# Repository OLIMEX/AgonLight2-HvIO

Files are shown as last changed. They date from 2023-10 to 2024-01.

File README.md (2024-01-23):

# AgonLight2-HvIO
High voltage optoisolated Four outputs and Four inputs and two Temperature sensor connectors for AgonLight2

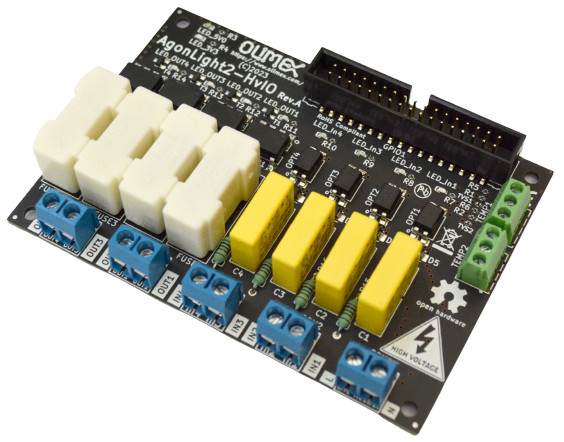
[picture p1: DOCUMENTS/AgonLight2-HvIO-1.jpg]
AgonLight2-HvIO-1


https://www.olimex.com/Products/Retro-Computers/AgonLight2-HvIO/open-source-hardware

Features:

* AgonLight GPIO connector
* Four SSR relays 240VAC 1A
* Four optoisolated inputs 120-240VAC
* Two Dallas18B20 temperature sensors
* LED output indicators
* LED input indicators
* Power supply 3.3V and 5V LED indicators
* Dimensions 100x70mm

## Licenses

* Hardware is released under CERN Open Hardware Licence Version 2 - Strongly Reciprocal, all silkscreen credits to Olimex should remain;
* Software is released under GPL3 Licensee
* Documentation is released under CC BY-SA 4.0

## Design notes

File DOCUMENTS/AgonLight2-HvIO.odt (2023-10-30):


AgonLight2-HvIO

User Manual

Rev.1.0 October 2023 olimex.com

# Introduction to AgonLight2-HvIO

AgonLight2-HvIO (https://www.olimex.com/Products/Retro-Computers/AgonLight2-HvIO/open-source-hardware) is Open Source Hardware board designed to work with AgonLight2.

It has these features:

- Four Solid-State-Relays SSR capable working on 240VAC with 1 A loads connected to AgonLight2 GPIO outputs
- SSR are with zero cross switching noise free
- Four opto isolated 240VAC inputs connected to AgonLight2 GPIO inputs
- Status LEDs for each output and input
- Status LEDs for 3.3V and 5V power supply of AginLight2
- Two Dallas DS18B20 temperature sensor inputs capable to work with SNS-TMP-DS18B20 (https://www.olimex.com/Products/Components/Sensors/Temperature/SNS-TMP-DS18B20/)
- Dimensions 100x70 mm

## Order codes for AgonLight2-HvIO:

AgonLight2-HvIO (https://www.olimex.com/Products/Retro-Computers/AgonLight2-HvIO/open-source-hardware) AgonLight high voltage IO board

SNS-TMP-DS18B20 (https://www.olimex.com/Products/Components/Sensors/Temperature/SNS-TMP-DS18B20/) temparature sensor

CABLE-IDC34-15CM not available yet cable between AgonLight2 and AgonLight2-HvIO

# HARDWARE

## AgonLight2-HvIO layout:

AgonLight2 GPIO connector

Power supply status LEDs

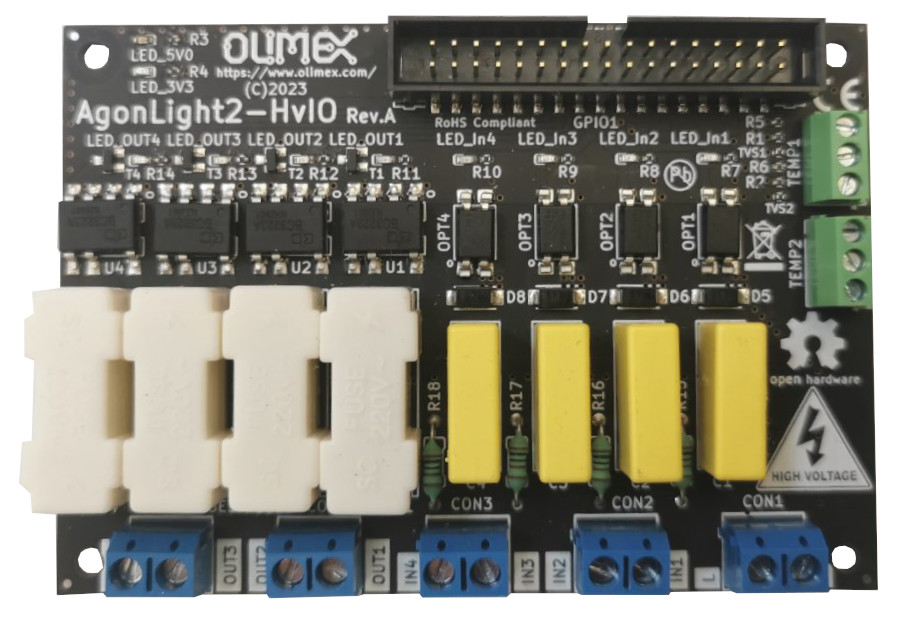
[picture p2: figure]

Temperature Sensors DS18B20

High voltage Outputs

High voltage Inputs

Power supply Live and Neutral

## AgonLight2-HvIO schematic

The schematic of AgonLight2-HvIO (https://www.olimex.com/Products/Retro-Computers/AgonLight2-HvIO/open-source-hardware) is on GitHub. On the next page there is picture of it.

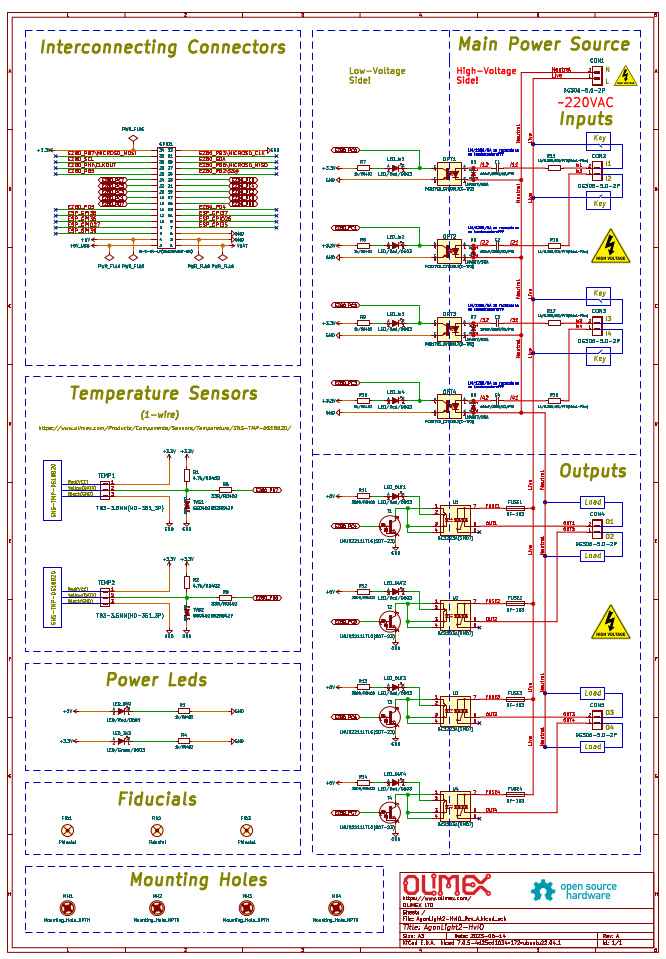
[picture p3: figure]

## AgonLight2 GPIO connector:

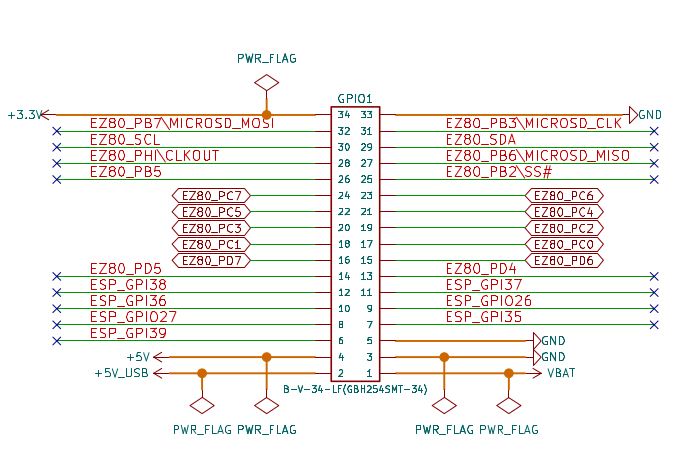
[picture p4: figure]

## AgonLight2-HvIO temperature sensors connector:

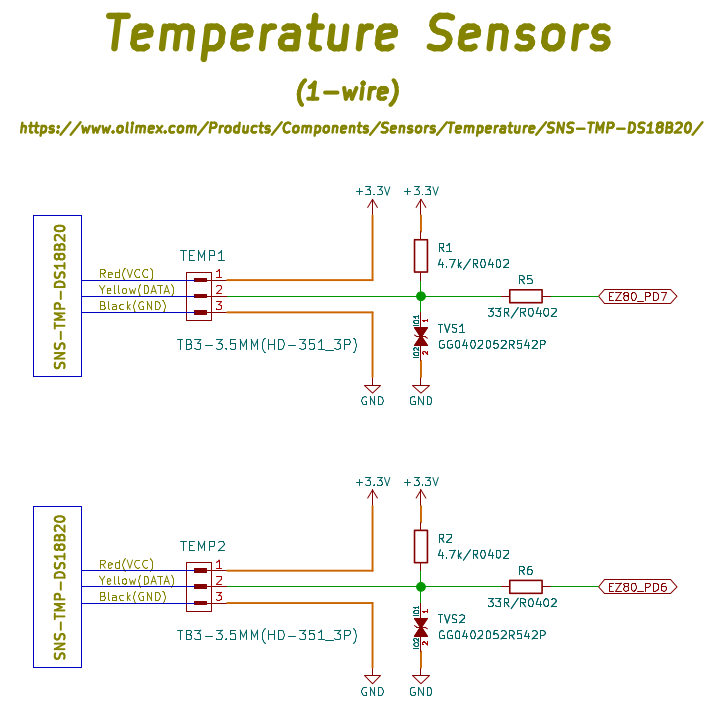
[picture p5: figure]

# SOFTWARE:

(https://www.olimex.com/Products/Retro-Computers/ESP32-SBC-FabGL/open-source-hardware)

## Reading the Inputs and Writing to the Outputs:

The outputs are assigned as follows:

OUT1 → PC4

OUT2 → PC5

OUT3 → PC6

OUT4 → PC7

The inputs are assigned as follows:

IN1 → PC0

IN2 → PC1

IN3 → PC2

IN4 → PC3

Port-C Data Direction Register is at address 159. To make port Input 1 should be written in the corresponding bit, to make it Output 0 should be written.

To make PC0-3 as inputs and PC4-7 as outputs the following basic command should be executed:

PUT 159 , %00001111

Port-C Data Value register is at address 158, so to read the Port-C status you can use:

PRINT GET(158)

and to set OUT1 = HIGH

PUT 158, %00010000

to set OUT1 = LOW

PUT 158, %00000000

Here is sample test program:

10 PC_DR% = &9E
20 PC_DDR% = &9F
30 PC_ALT1% = &A0
40 PC_ALT2% = &A1
50 PD_DR% = &A2
60 PD_DDR% = &A3
70 PD_ALT1% = &A4
80 PD_ALT2% = &A5
90 PUT PC_DDR%, &F
100 PUT PC_ALT1%, &00
110 PUT PC_ALT2%, &00
120 PUT PD_DDR%, &FF
130 I=0
140 Input=0
150 PCD = GET(PC_DR%)
160 Input = Input OR ((PCD EOR &F) AND &F)
170 PRINT "PCD="; PCD; " Input=";Input; " I="; I
180 I=I+1
190 IF (I<10) THEN GOTO 150
200 PUT PC_DR%, Input*16
210 Temp = GET(PD_DR%) AND &C0
220 IF (Temp = &C0) THEN GOTO 130
230 PUT PC_DR%, (GET(PC_DR%) AND &3F) OR ((GET(PD_DR%) AND &C0)EOR &C0)
240 PCD = GET(PC_DR%) AND &F
250 IF (PCD=15) THEN GOTO 230 ELSE GOTO 130

# Revision History

Revision 1.0 October 2023 initial

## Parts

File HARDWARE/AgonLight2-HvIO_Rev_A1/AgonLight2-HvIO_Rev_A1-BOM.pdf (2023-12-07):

AgonLight2-HvIO_Rev_A1-BOM | 10/30/2023
Quantity | Designation | Footprint | Designator
2 | 33R/R0402 | R0402 | R5,R6
4 | 200R/R0402 | R0402 | R11,R12,R13,R14
4 | 1k/0.25W/1%/PTH(Metal-Film) | R_0.25W_PTH | R15,R16,R17,R18
6 | 1k/R0402 | R0402 | R3,R4,R7,R8,R9,R10
2 | 4.7k/R0402 | R0402 | R1,R2
4 | 100nF/250V/X2/PTH | C600-700x250mils | C1,C2,C3,C4
4 | 1N4007/SMA | SMA | D5,D6,D7,D8
2 | GG0402052R542P | D0402 | TVS1,TVS2
9 | LED/Red/0603 | LED_0603 | LED_In1,LED_In2,LED_In3,LED_In4, LED_OUT1,LED_OUT2,LED_OUT3, LED_OUT4,LED_5V0
1 | LED/Green/0603 | LED_0603 | LED_3V3
4 | LMUN2211LT1G(SOT-23) | SOT-23 | T1,T2,T3,T4
4 | BC3213A(SMD7) | SMD7 | U1,U2,U3,U4
4 | PC817CS_CYPC817(C-TP2) | H11A817C_SMD | OPT1,OPT2,OPT3,OPT4
4 | BF-103 | FUSE-HOLDER | FUSE1,FUSE2,FUSE3,FUSE4
1 | B-V-34-LF(GBH254SMT-34) | GBH254SMT-34 | GPIO1
5 | DG306-5.0-2P | TB2-DG306-5.0_2P | CON1,CON2,CON3,CON4,CON5
2 | TB3-3.5ММ(HD-351_3P) | TB3-3.5mm | TEMP1,TEMP2

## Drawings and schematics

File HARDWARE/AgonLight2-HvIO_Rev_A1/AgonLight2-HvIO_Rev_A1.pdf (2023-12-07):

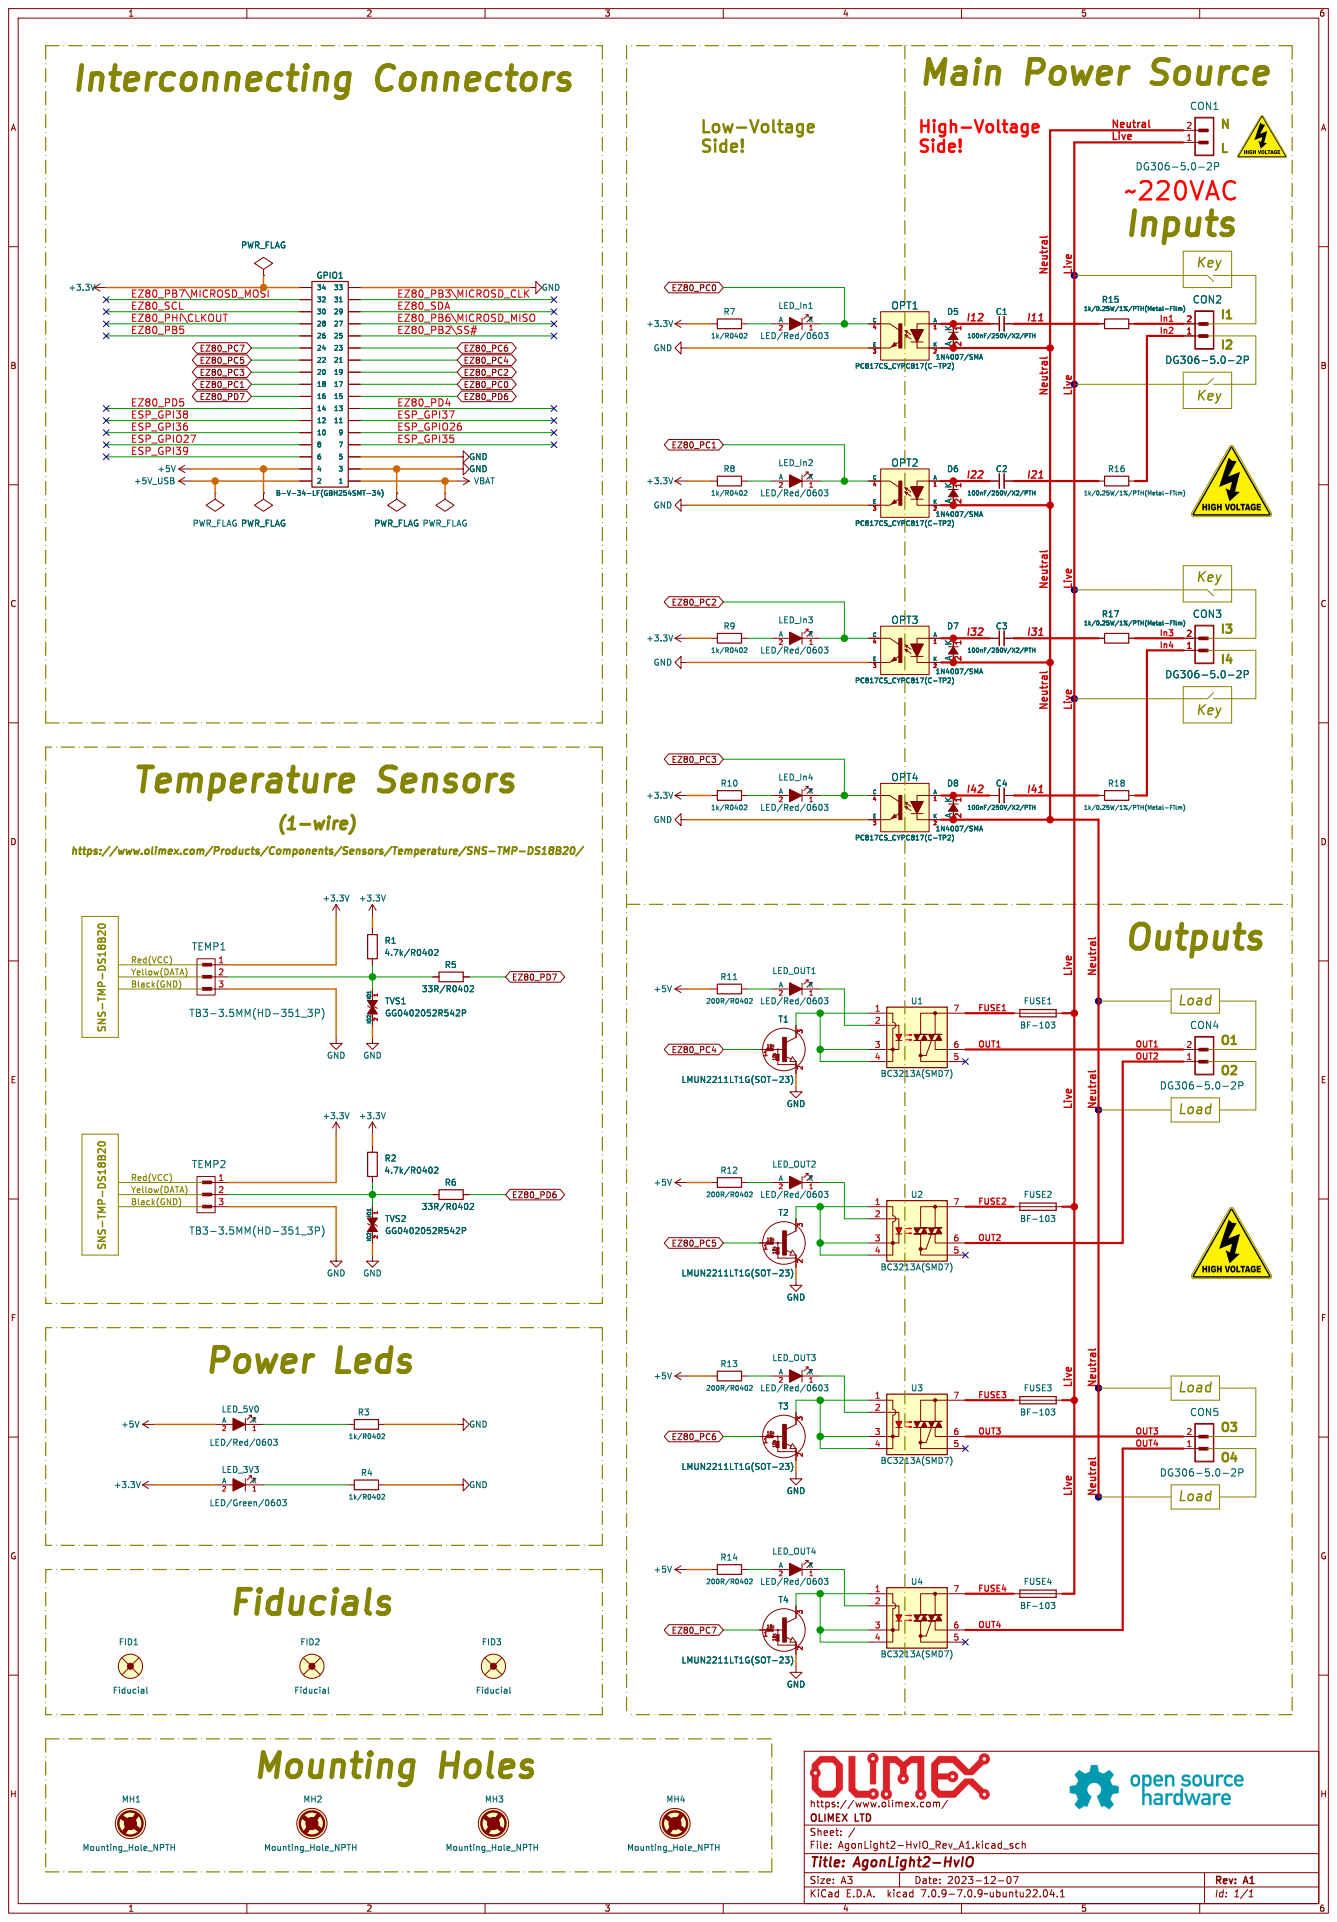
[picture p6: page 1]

https://www.olimex.com/Products/Components/Sensors/Temperature/SNS-TMP-DS18B20/ Temperature Sensors

Outputs Red(VCC) Black(GND) Yellow(DATA)
Mounting Holes SNS-TMP-DS18B20

Yellow(DATA) Red(VCC) Black(GND)

https://www.olimex.com/
File: AgonLight2-HvIO_Rev_A1.kicad_sch Sheet: / OLIMEX LTD

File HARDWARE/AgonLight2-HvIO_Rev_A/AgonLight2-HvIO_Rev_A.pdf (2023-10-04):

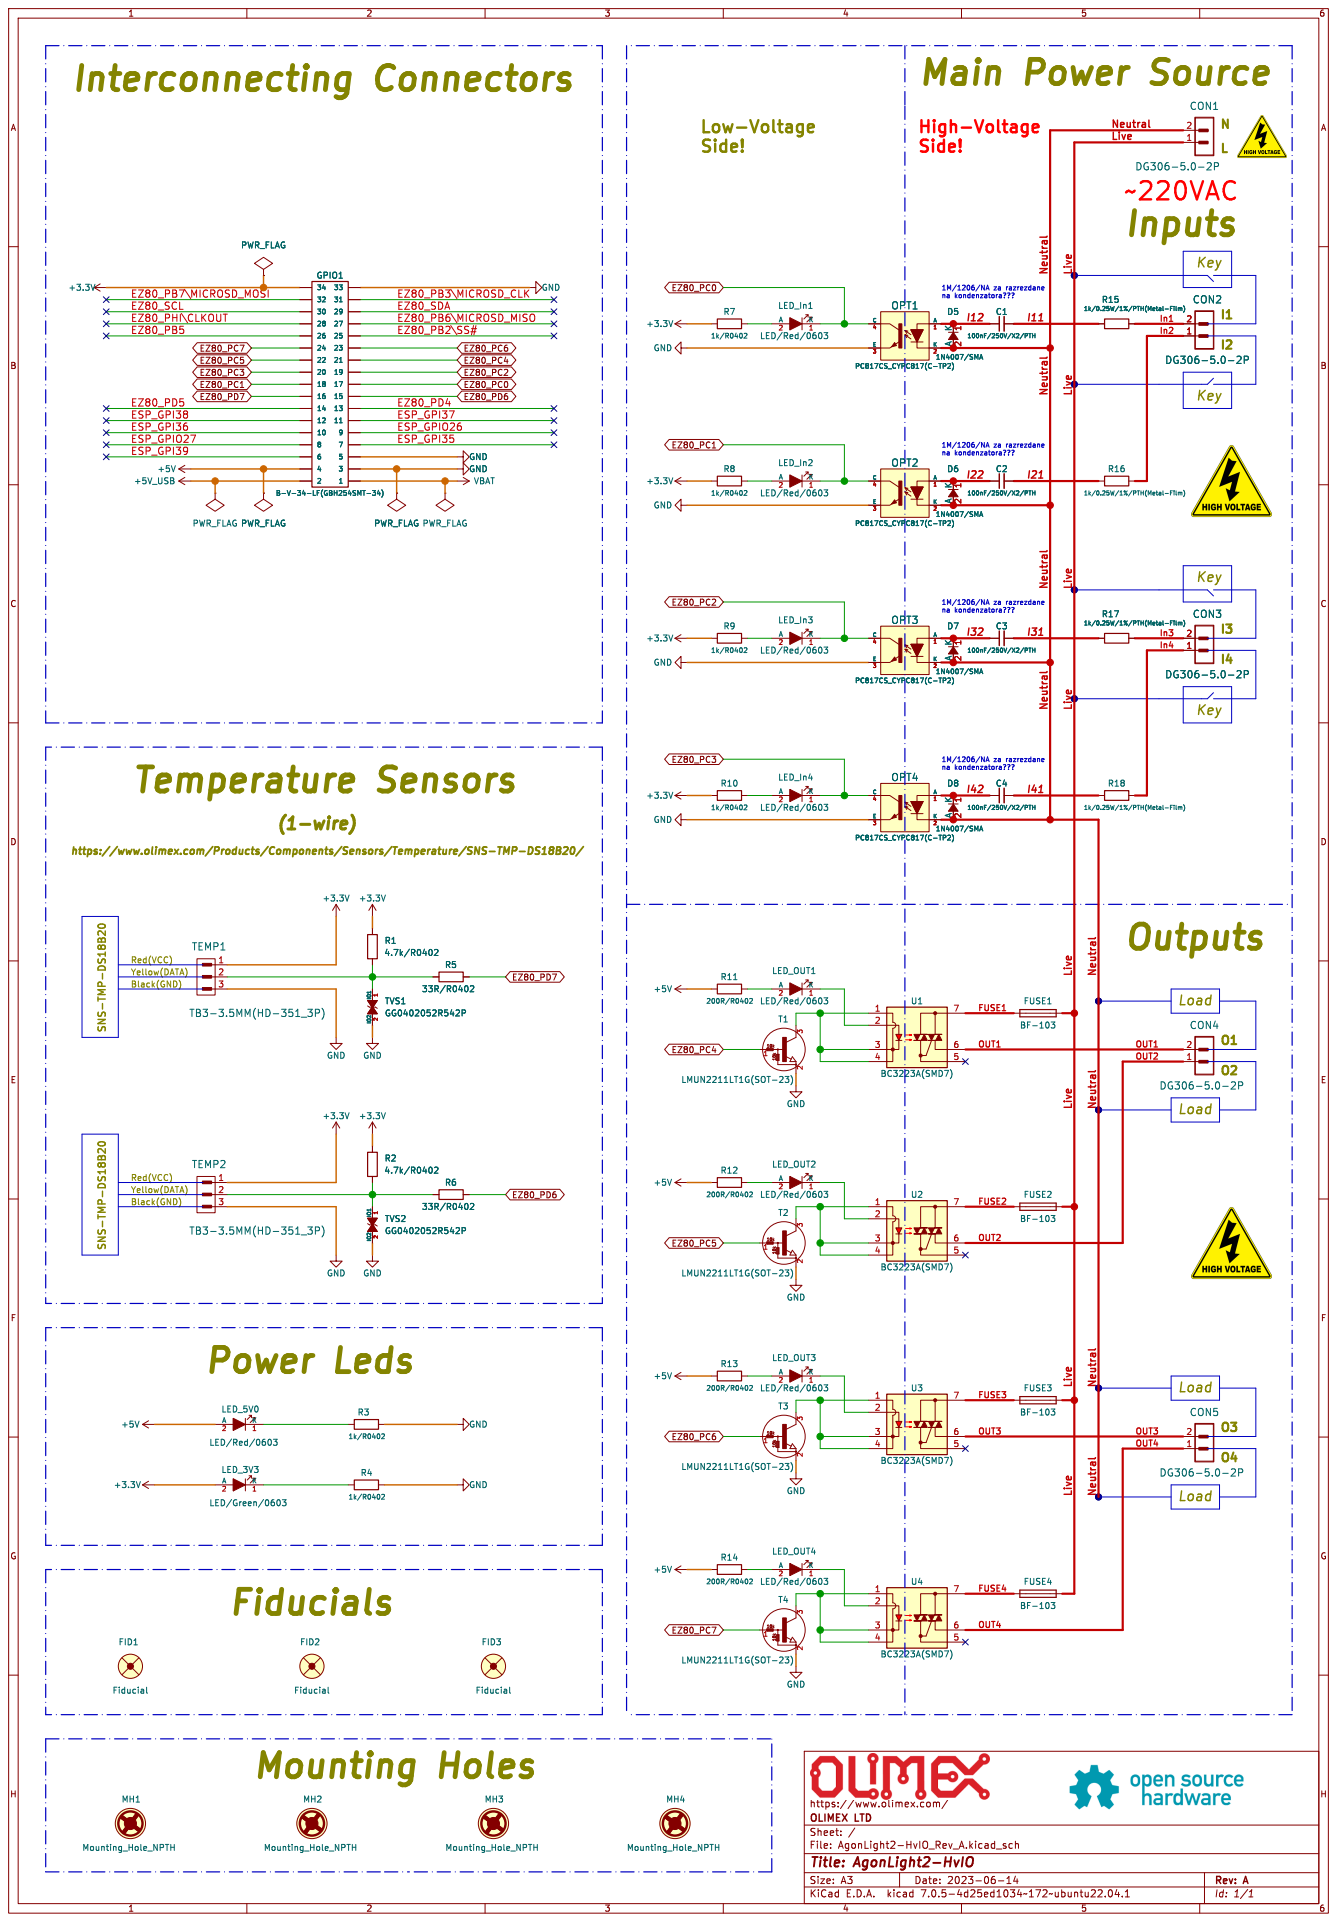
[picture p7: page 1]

https://www.olimex.com/Products/Components/Sensors/Temperature/SNS-TMP-DS18B20/ SNS-TMP-DS18B20

Red(VCC) Yellow(DATA)

Red(VCC) Black(GND)

https://www.olimex.com/
File: AgonLight2-HvIO_Rev_A.kicad_sch Sheet: / OLIMEX LTD

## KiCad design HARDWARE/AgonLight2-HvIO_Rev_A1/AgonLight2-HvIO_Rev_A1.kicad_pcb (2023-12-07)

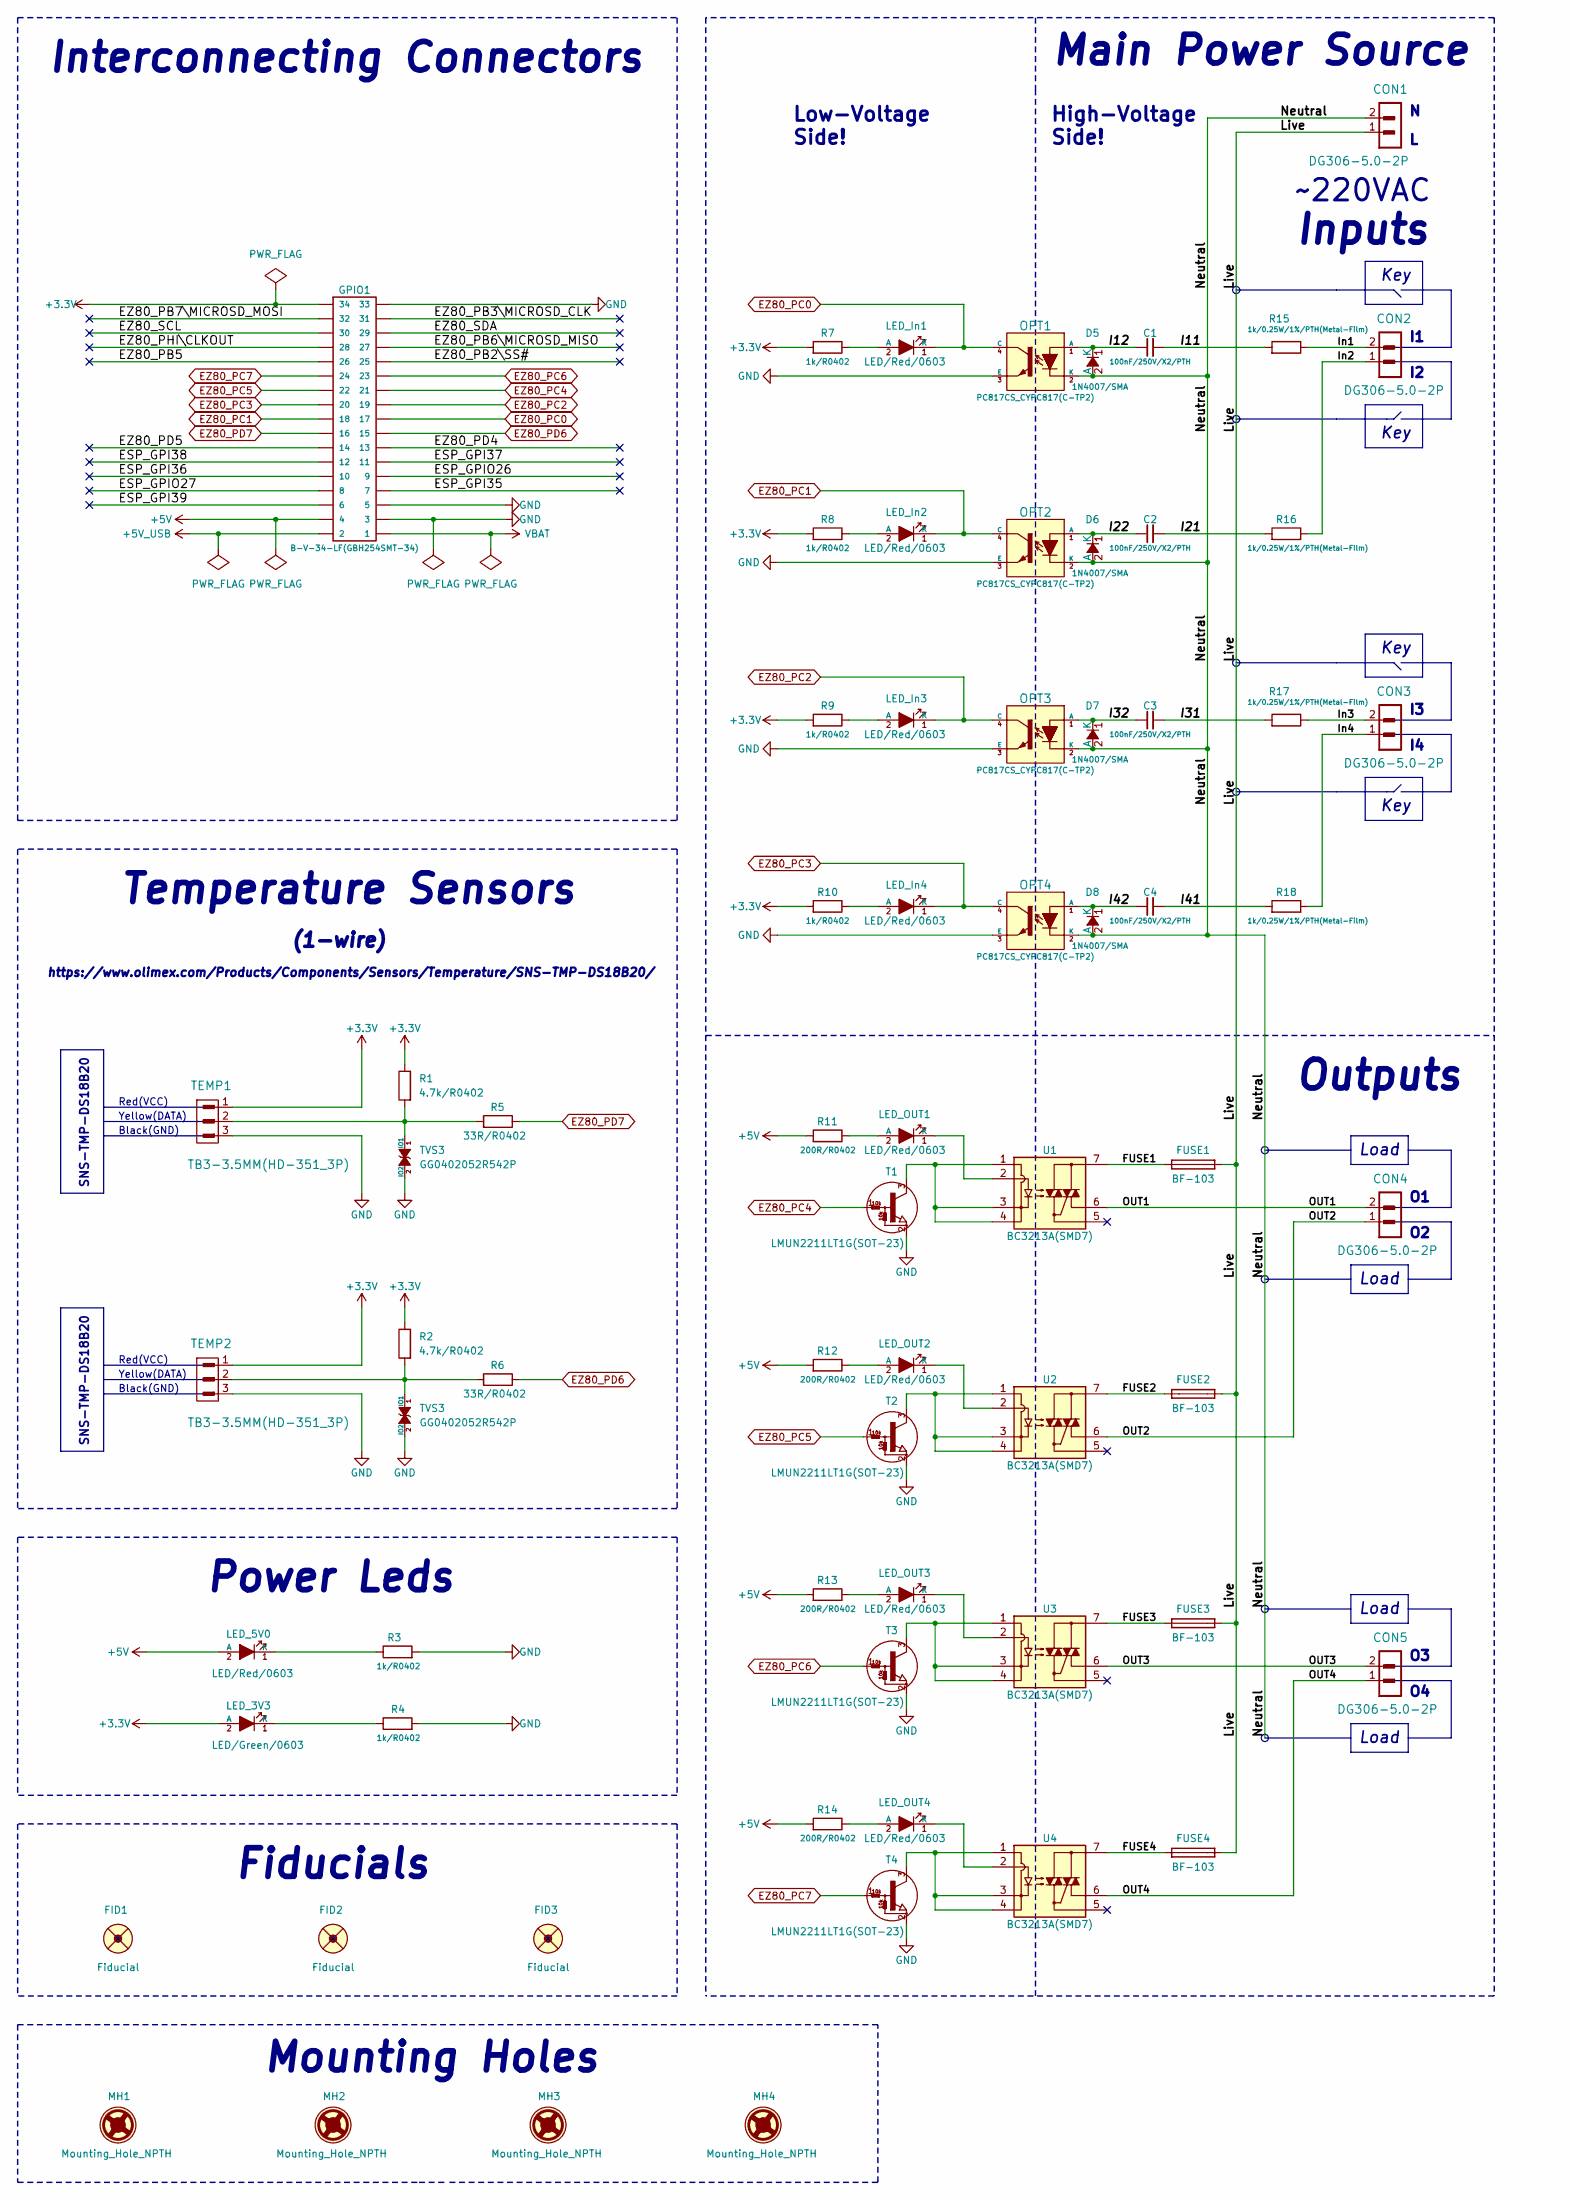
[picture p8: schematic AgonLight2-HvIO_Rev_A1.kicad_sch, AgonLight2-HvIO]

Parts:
C1, C2, C3, C4: 100nF/250V/X2/PTH; C600-700x250mils
CON1, CON2, CON3, CON4, CON5: DG306-5.0-2P; TB2-DG306-5.0_2P
D5, D6, D7, D8: 1N4007/SMA; SMA-KA
FID1, FID2, FID3: Fiducial; Fiducial1x3
FUSE1, FUSE2, FUSE3, FUSE4: BF-103; FUSE-HOLDER_BF-103
GPIO1: B-V-34-LF(GBH254SMT-34); GBH-254-SMT-34
LED_3V3: LED/Green/0603; LED_0603_KA
LED_5V0: LED/Red/0603; LED_0603_KA
LED_In1, LED_In2, LED_In3, LED_In4: LED/Red/0603; LED_0603_KA
LED_OUT1, LED_OUT2, LED_OUT3, LED_OUT4: LED/Red/0603; LED_0603_KA
MH1, MH2, MH3, MH4: Mounting_Hole_NPTH; Mounting_Hole_Drill-3.3mm_Clerance-7mm
OPT1, OPT2, OPT3, OPT4: PC817CS_CYPC817(C-TP2); H11A817C_SMD(PC817X3NIP06)_FP
R1, R2: 4.7k/R0402; R_0402_5MIL_DWS
R3, R4, R7, R8, R9, R10: 1k/R0402; R_0402_5MIL_DWS
R5, R6: 33R/R0402; R_0402_5MIL_DWS
R11, R12, R13, R14: 200R/R0402; R_0402_5MIL_DWS
R15, R16, R17, R18: 1k/0.25W/1%/PTH(Metal-Film); R_0.25W_PTH
T1, T2, T3, T4: LMUN2211LT1G(SOT-23); SOT23
TEMP1, TEMP2: TB3-3.5ММ(HD-351_3P); TB3-3.5mm
TVS3: GG0402052R542P; D_0402_5MIL_DWS
U1, U2, U3, U4: BC3213A(SMD7); SMD7_L9.70xW6.40_P2.54mm

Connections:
+3.3V: GPIO1.34, LED_3V3.2 (A), R1.1, R2.1, R7.2, R8.2, R9.2, R10.2, TEMP1.1, TEMP2.1
+5V: GPIO1.4, LED_5V0.2 (A), R11.2, R12.2, R13.2, R14.2
+5V_USB: GPIO1.2
/ESP_GPI35: GPIO1.7
/ESP_GPI36: GPIO1.10
/ESP_GPI37: GPIO1.11
/ESP_GPI38: GPIO1.12
/ESP_GPI39: GPIO1.6
/ESP_GPIO26: GPIO1.9
/ESP_GPIO27: GPIO1.8
/EZ80_PB2\SS#: GPIO1.25
/EZ80_PB3\MICROSD_CLK: GPIO1.31
/EZ80_PB5: GPIO1.26
/EZ80_PB6\MICROSD_MISO: GPIO1.27
/EZ80_PB7\MICROSD_MOSI: GPIO1.32
/EZ80_PD4: GPIO1.13
/EZ80_PD5: GPIO1.14
/EZ80_PHI\CLKOUT: GPIO1.28
/EZ80_SCL: GPIO1.30
/EZ80_SDA: GPIO1.29
/FUSE1: FUSE1.1, U1.7
/FUSE2: FUSE2.1, U2.7
/FUSE3: FUSE3.1, U3.7
/FUSE4: FUSE4.1, U4.7
/I11: C1.2, R15.2
/I12: C1.1, D5.1 (K), OPT1.1 (A)
/I21: C2.2, R16.2
/I22: C2.1, D6.1 (K), OPT2.1 (A)
/I31: C3.2, R17.2
/I32: C3.1, D7.1 (K), OPT3.1 (A)
/I41: C4.2, R18.2
/I42: C4.1, D8.1 (K), OPT4.1 (A)
/In1: CON2.2, R15.1
/In2: CON2.1, R16.1
/In3: CON3.2, R17.1
/In4: CON3.1, R18.1
/Live: CON1.1, FUSE1.2, FUSE2.2, FUSE3.2, FUSE4.2
/Neutral: CON1.2, D5.2 (A), D6.2 (A), D7.2 (A), D8.2 (A), OPT1.2 (K), OPT2.2 (K), OPT3.2 (K), OPT4.2 (K)
/OUT1: CON4.2, U1.6
/OUT2: CON4.1, U2.6
/OUT3: CON5.2, U3.6
/OUT4: CON5.1, U4.6
EZ80_PC0: GPIO1.17, LED_In1.1 (K), OPT1.4 (C)
EZ80_PC1: GPIO1.18, LED_In2.1 (K), OPT2.4 (C)
EZ80_PC2: GPIO1.19, LED_In3.1 (K), OPT3.4 (C)
EZ80_PC3: GPIO1.20, LED_In4.1 (K), OPT4.4 (C)
EZ80_PC4: GPIO1.21, T1.1 (B)
EZ80_PC5: GPIO1.22, T2.1 (B)
EZ80_PC6: GPIO1.23, T3.1 (B)
EZ80_PC7: GPIO1.24, T4.1 (B)
EZ80_PD6: GPIO1.15, R6.1
EZ80_PD7: GPIO1.16, R5.1
GND: GPIO1.3, GPIO1.5, GPIO1.33, OPT1.3 (E), OPT2.3 (E), OPT3.3 (E), OPT4.3 (E), R3.2, R4.2, T1.2 (E), T2.2 (E), T3.2 (E), T4.2 (E), TEMP1.3, TEMP2.3; also elsewhere on the board
unnamed: LED_3V3.1 (K), R4.1
unnamed: LED_5V0.1 (K), R3.1
unnamed: LED_In1.2 (A), R7.1
unnamed: LED_In2.2 (A), R8.1
unnamed: LED_In3.2 (A), R9.1
unnamed: LED_In4.2 (A), R10.1
unnamed: LED_OUT1.2 (A), R11.1
unnamed: LED_OUT1.1 (K), U1.2
unnamed: LED_OUT2.2 (A), R12.1
unnamed: LED_OUT2.1 (K), U2.2
unnamed: LED_OUT3.2 (A), R13.1
unnamed: LED_OUT3.1 (K), U3.2
unnamed: LED_OUT4.2 (A), R14.1
unnamed: LED_OUT4.1 (K), U4.2
unnamed: T1.3 (C), U1.1, U1.3, U1.4
unnamed: T2.3 (C), U2.1, U2.3, U2.4
unnamed: T3.3 (C), U3.1, U3.3, U3.4
unnamed: T4.3 (C), U4.1, U4.3, U4.4
unnamed 71: R1.2, R5.2, TEMP1.2; also elsewhere on the board
unnamed 72: R2.2, R6.2, TEMP2.2; also elsewhere on the board
VBAT: GPIO1.1

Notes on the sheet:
Key
Inputs
Mounting Holes
Load
Red(VCC)
SNS-TMP-DS18B20
Main Power Source
Black(GND)
Yellow(DATA)
Outputs
Low-Voltage Side!
Fiducials
https://www.olimex.com/Products/Components/Sensors/Temperature/SNS-TMP-DS18B20/
Power Leds
~220VAC
(1-wire)
High-Voltage Side!
Interconnecting Connectors
Temperature Sensors

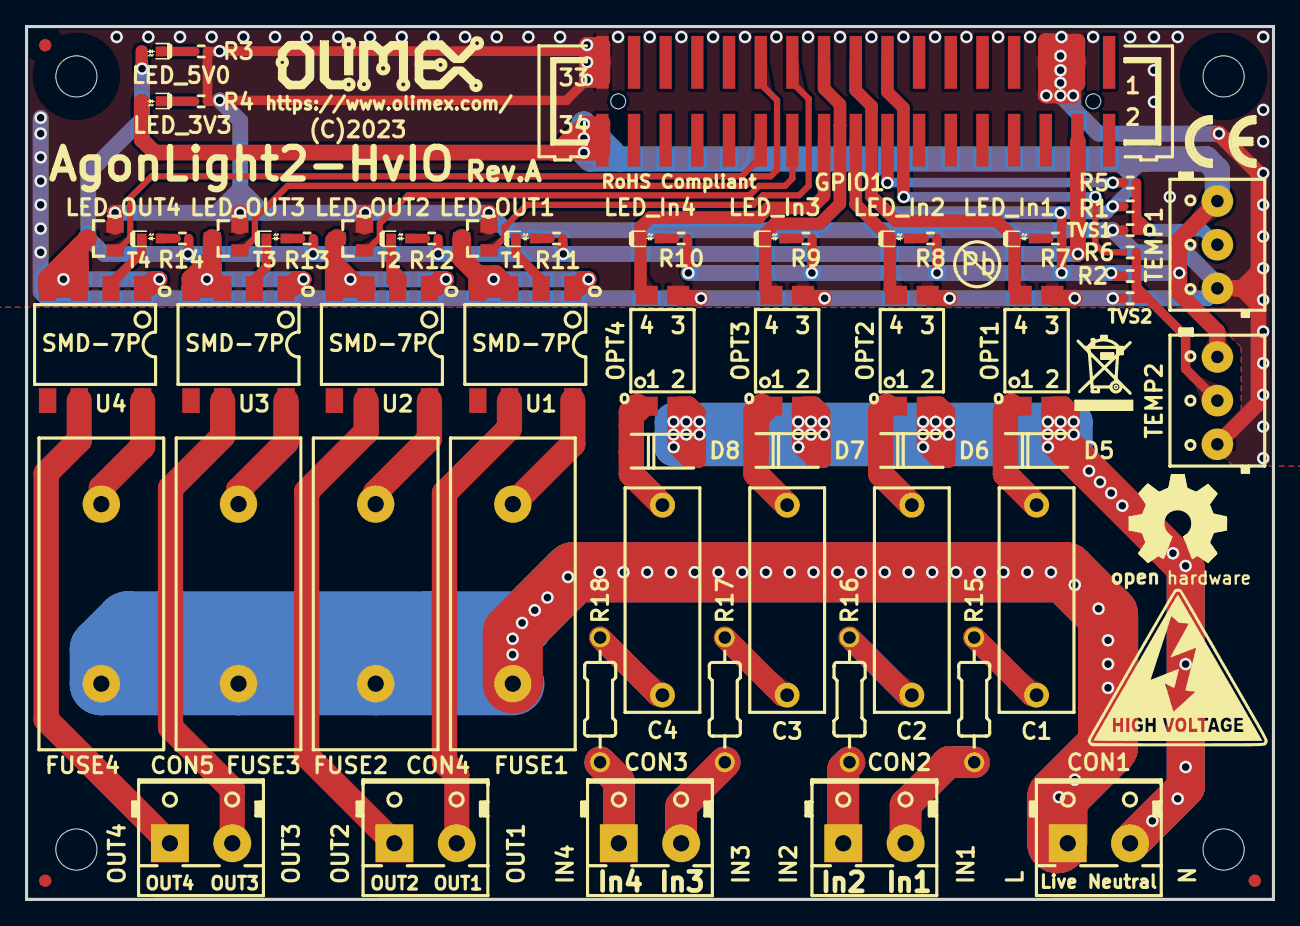
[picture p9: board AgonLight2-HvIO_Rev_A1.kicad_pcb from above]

Board: 2 copper layers, 100.0 x 70.0 mm, 74 parts (0 on the bottom side), 55 nets.

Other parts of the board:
Logo_OLIMEX_TB: Logo_OLIMEX_TB
Sign_CE: CE_Sign
Sign_OSHW_8x8: Sign_OSHW_8x8
Sign_PB-Free: Sign_PB-Free
Sign_RecycleBin_1: Sign_RecycleBin_1
TVS1, TVS2: GG0402052R542P; D_0402_5MIL_DWS

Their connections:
GND: TVS1.2 (IO2), TVS2.2 (IO2); also elsewhere on the board
unnamed 71: TVS1.1 (IO1); also elsewhere on the board
unnamed 72: TVS2.1 (IO1); also elsewhere on the board

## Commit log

2023-10-04 user manual, cad files
    [AgonLight2-HvIO_Rev_A-BOM.ods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]
2023-12-07 Update
    Revision A1
    [AgonLight2-HvIO_Rev_A-B_Cu.gbr, AgonLight2-HvIO_Rev_A-B_Mask.gbr, AgonLight2-HvIO_Rev_A-B_Paste.gbr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]

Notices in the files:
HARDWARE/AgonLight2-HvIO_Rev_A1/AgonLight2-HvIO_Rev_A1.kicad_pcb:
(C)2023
